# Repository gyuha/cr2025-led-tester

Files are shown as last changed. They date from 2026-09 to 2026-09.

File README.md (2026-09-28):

# cr2025-led-tester
CR2025 LED Tester - 3D Printer

CR2025 코인셀 하나와 파란 5mm LED로, 검사 기판에 납땜된 **1N4148WS(SOD-323) 다이오드의 방향**을 확인하는 3D 프린팅 테스터입니다. 노즈 끝의 두 철사를 다이오드 양쪽 패드에 대면, 방향이 맞을 때 위쪽 LED가 켜집니다. 납땜 없이 LED·저항에서 잘라낸 다리를 케이스 홈에 눌러 끼워 만듭니다.

## 파일

| 파일 | 내용 |
|---|---|
| `stl/tester.stl` | 본체. 배터리 슬롯, LED 받침, 철사 홈, 노즈 |
| `stl/cover.stl` | 케이블 커버. 노즈 구간의 철사를 덮어 누르는 별도 부품 |
| `stl/nose-coupon.stl` | 노즈 시험편. 프로브 간격과 홈 폭을 맞출 때만 씁니다 |
| [docs/assembly.md](docs/assembly.md) | 조립·사용 안내 전체 (인쇄 설정, 조립 순서, 판정 규칙, 문제 해결) |
| [docs/coupon.md](docs/coupon.md) | 노즈 시험편 사용법과 결과 기록 (간격 2.2mm, 홈 폭 0.5mm로 확정) |
| `cad/` | 모델 원본. FreeCAD `freecadcmd`로 실행하는 Python 스크립트와 치수 검사 |

## 준비물

- **인쇄**: `stl/tester.stl`, `stl/cover.stl`
  - Bambu, PLA, 0.4mm 노즐, 레이어 0.12–0.16mm, 서포트 없음
  - 본체는 평평한 뒷면을 바닥에, 커버는 파일 그대로(판이 바닥, 핀이 위) 놓습니다.
- **부품**: CR2025 1개, 파란 5mm LED 1개, 잘라낸 다리 2가닥
  - 연장 다리 A는 약 32mm, 철사 B는 약 30mm가 필요합니다. 짧으면 Ø0.5 구리 단선도 괜찮습니다.
- **도구**: 니퍼, 롱노즈 플라이어, 핀셋

## 철사 연결 방법

철사 4가닥을 케이스 홈에 눌러 끼우고, 노즈 구간은 케이블 커버로 덮은 뒤, **배터리는 맨 마지막에** 넣습니다. 아래 그림은 실제 모델(`stl/tester.stl`, `stl/cover.stl`)에 철사를 색깔별로 그려 넣은 것입니다.

| 색 | 철사 | 가는 곳 |
|---|---|---|
| 🔴 빨강 | **② 애노드 다리**: LED 긴 다리 | 뒤쪽 터널 → 배터리 자리 안쪽 뒷벽 홈 → 배터리 **뒷면(+)** |
| 🟠 주황 | **캐소드 다리**: LED 짧은 다리 | 앞면 홈 A → ① 이음부 |
| 🟡 노랑 | **① 연장 다리 A**: 잘라낸 다리 1가닥 | 이음부에서 주황과 나란히 → 홈 A → 노즈 끝 **A** (▶ 쪽) |
| 🟢 초록 | **③ 철사 B**: 잘라낸 다리 1가닥 | 노즈 끝 **B** (\| 쪽) → 홈 B → ③ 통과 구멍 → 천장 접촉 홈에서 배터리 **앞면(−)**에 선으로 닿음 |

### 완성된 모습 (정면, 홈이 있는 면)

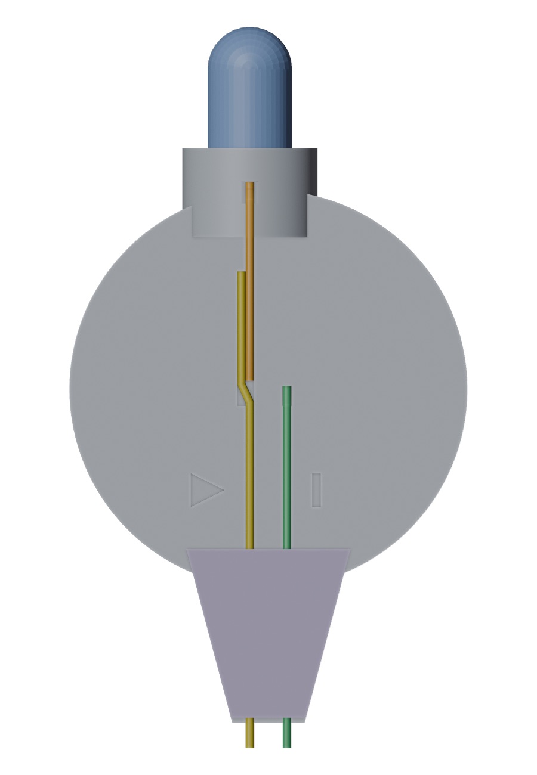
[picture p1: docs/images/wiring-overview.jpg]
철사를 모두 넣은 정면


- 맨 위가 **LED**입니다. 주황 캐소드 다리가 앞면 **홈 A**로 내려옵니다.
- 홈이 두 배로 넓은 구간이 **① 이음부**입니다. 여기서 노랑 연장 다리가 주황 옆에 나란히 눌려 이어지고, 노즈 끝 **A**까지 내려갑니다.
- 노즈 구간(약 10mm)은 별도 부품인 **케이블 커버**(보라색)가 덮습니다. 노랑과 초록을 열린 홈에 올려놓고 커버를 꽂으면, 끝으로 패드를 눌러도 철사가 빠지지 않습니다. 그래서 정면 그림에서는 노즈 속 철사가 커버에 가려 끝에서만 보입니다.
- 초록 철사 B는 오른쪽 홈 B에 들어갑니다. 홈 B가 끝나는 곳의 작은 구멍이 **③ 통과 구멍**입니다. 철사 B의 끝 5mm는 이 구멍을 비스듬히 지나 앞판 안쪽 천장의 접촉 홈에 눕고, 배터리 (−) 면에 선으로 닿습니다. 반대쪽 끝은 노즈 **B**입니다.
- 빨강 애노드 다리는 앞판에 가려 정면에서는 보이지 않습니다. 아래 2단계의 단면 그림을 보세요.

전류는 다음 순서로 흐릅니다.

```
배터리(+) → 빨강 → LED → 주황 → 노랑 → 끝 A → 측정 대상 다이오드 → 끝 B → 초록 → 배터리(−)
```

### 1. LED 다리 벌리기

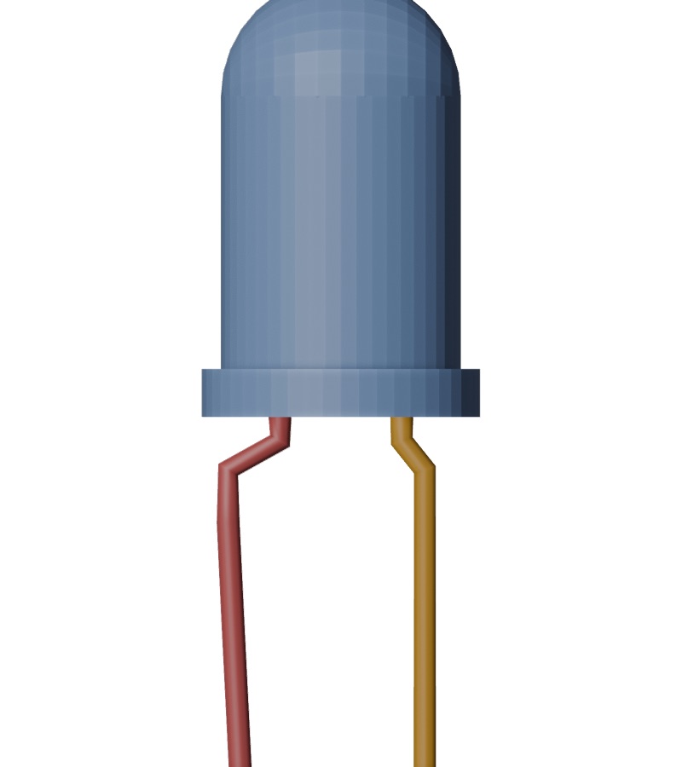
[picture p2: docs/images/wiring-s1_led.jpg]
LED 다리를 앞뒤로 벌린 모습


옆에서 본 모습입니다(왼쪽 = 케이스 뒤, 오른쪽 = 앞). 플랜지 바로 아래에서 **긴 다리(애노드, 빨강)**를 **뒤로 약 1mm**, **짧은 다리(캐소드, 주황)**를 **앞으로 약 0.5mm** 꺾습니다. 캐소드는 LED 플랜지의 **평평한 쪽**에 있는 다리입니다.

### 2. LED 꽂기와 ② 애노드 다리 (단면)

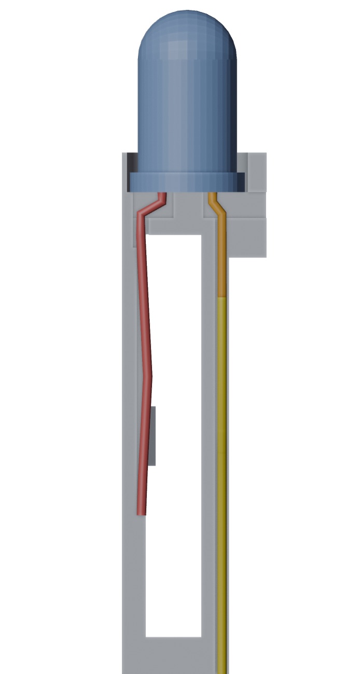
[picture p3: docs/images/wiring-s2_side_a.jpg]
LED 줄에서 자른 단면: 애노드와 캐소드 경로


케이스를 LED 줄에서 세로로 자른 단면입니다. 왼쪽이 뒤, 오른쪽이 앞이고, 가운데 빈 곳이 배터리 자리입니다.

- LED를 받침 위에서 내려 꽂습니다.
- **빨강**은 뒤쪽 터널을 지나 배터리 자리 안쪽 **뒷벽 홈**을 따라 내려갑니다. **주황**은 앞면 홈 A로 들어갑니다.
- 빨강은 홈 끝(배터리 중심에서 약 4mm 아래)에서 자르고, 가운데를 배터리 쪽으로 **약 0.5mm 활처럼** 휘게 합니다. 이 휨이 배터리 (+) 면을 누르는 스프링입니다.

### 3. ① 이음부: 주황 + 노랑

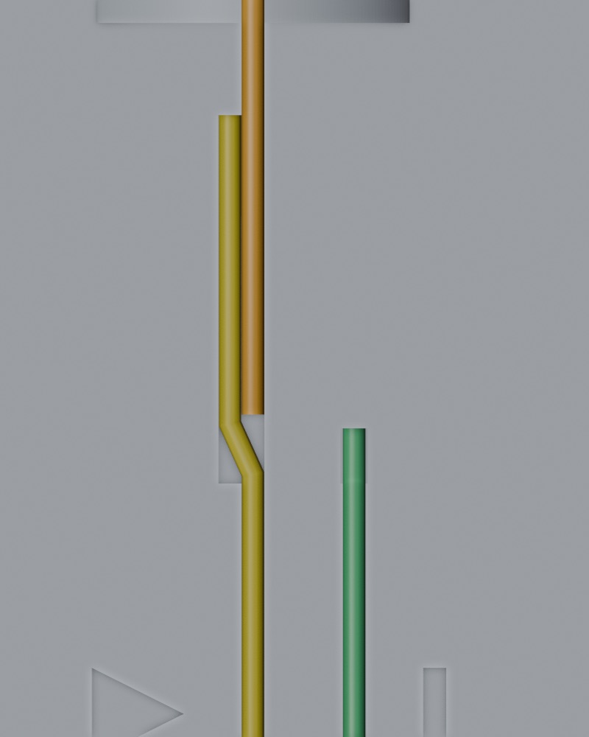
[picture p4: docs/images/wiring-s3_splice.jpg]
이음부 확대: 주황과 노랑이 나란히


- **주황**은 넓은 구간의 아래쪽 끝보다 **약 1.5mm 위**에서 자릅니다.
- **노랑**(약 32mm 다리)은 넓은 구간 위쪽 끝부터 주황 **왼쪽 옆에 나란히** 눌러 넣습니다.
- 주황이 끝난 아래에서 홈 가운데로 살짝 옮긴 뒤, 홈 A를 따라 노즈 끝까지 **위에서 눌러** 넣습니다.
- 노즈 끝으로 나온 부분은 **1.5mm** 남기고 **사선으로** 자릅니다.

두 다리가 약 6mm 맞붙어 전기가 통합니다.

### 4. ③ 철사 B: 통과 구멍을 지나 천장 홈에 눕히기 (단면)

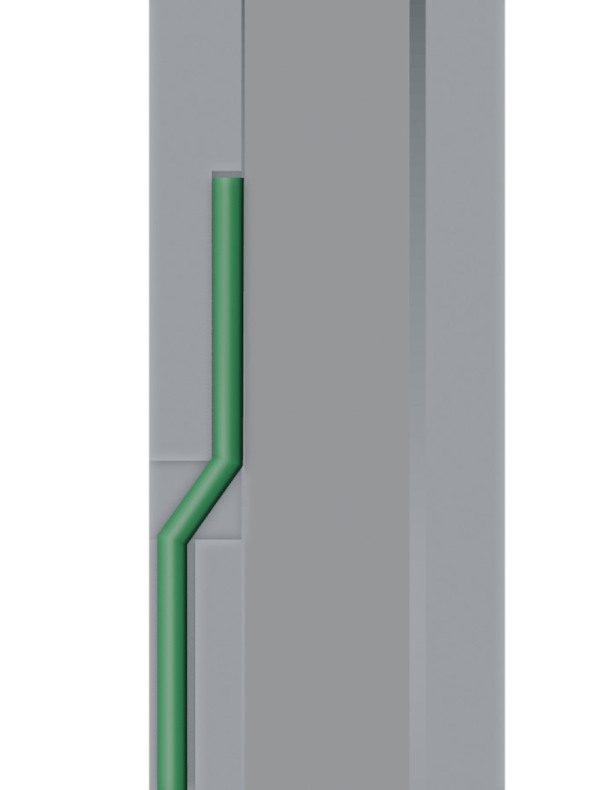
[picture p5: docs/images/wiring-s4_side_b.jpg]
철사 B 줄에서 자른 단면: 통과 구멍을 지나 천장 홈에 누운 끝 5mm


철사 B 줄에서 자른 단면입니다. 왼쪽이 앞, 오른쪽이 뒤이고, 가운데 진한 회색이 배터리입니다.

- 잘라낸 다리(약 30mm)의 한쪽 끝에서 **약 5mm**, **약 6mm** 되는 두 곳을 반대 방향으로 조금씩 꺾어 **계단(크랭크) 모양**을 만듭니다. 끝 5mm가 나머지보다 약 0.9mm 낮아집니다.
- 끝 5mm를 ③ 통과 구멍으로 **위쪽을 향해 비스듬히** 밀어 넣습니다. 그다음 슬롯 쪽에서 핀셋으로 천장 안쪽 **접촉 홈**에 눌러 눕힙니다.
- 배터리를 넣으면 뒤쪽 빨강의 휨이 배터리를 앞으로 밀어, 누운 약 4.4mm 구간 전체가 배터리 **앞면(−)**에 **선으로** 닿습니다.
- 나머지는 구멍에서 노즈 끝까지 홈 B에 **위에서 눌러** 넣고, 노즈 끝으로 나온 부분은 1.5mm 남겨 사선으로 자릅니다.

### 5. 케이블 커버 덮기

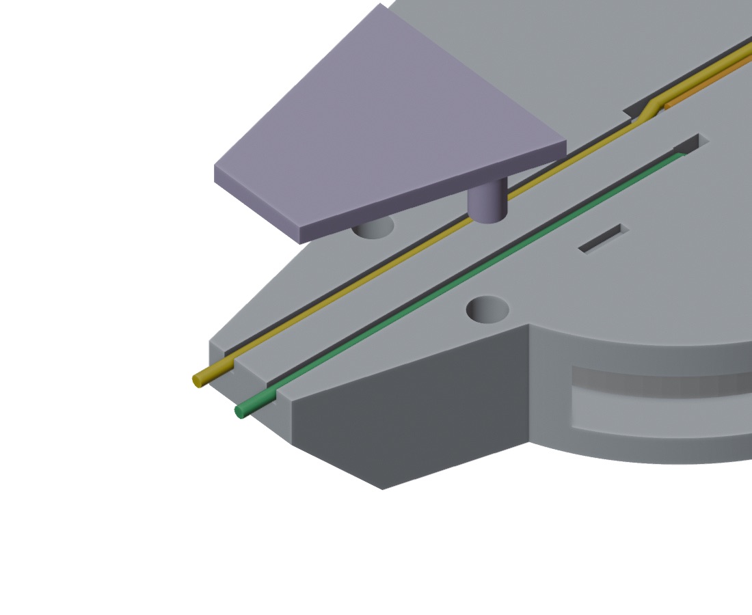
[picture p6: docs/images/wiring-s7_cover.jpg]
케이블 커버를 노즈에 덮는 분해도


케이블 커버(`stl/cover.stl`)는 노즈 앞면을 덮는 0.8mm 판에 핀 2개가 달린 별도 부품입니다.

- 노랑과 초록을 홈에 다 넣은 뒤, 커버의 판이 노즈 앞면을 향하게 하고 **핀 2개를 노즈 윗부분의 고정 구멍**에 맞춰 끝까지 눌러 꽂습니다.
- 판이 노즈 구간의 두 철사를 홈 속으로 눌러 잡습니다. 커버는 노즈 끝 0.3mm 앞에서 끝나서, 철사 끝 1.5mm는 그대로 나옵니다.
- 철사를 고칠 때는 커버 가장자리를 손톱으로 들어 빼면 됩니다.
- 핀이 너무 빡빡하면 Ø1.5 드릴로 구멍을 한 번 돌려 주고, 헐거우면 핀에 테이프를 한 겹 감습니다.

### 6. 배터리는 맨 마지막 → 오른쪽 슬롯

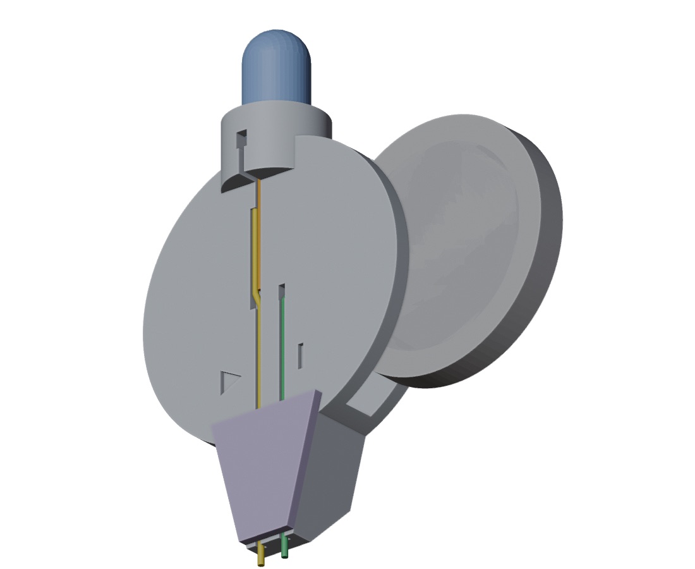
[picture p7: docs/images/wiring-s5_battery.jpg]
배터리를 오른쪽 슬롯으로 밀어 넣기


각인이 있는 **(+) 면을 뒤(바닥 쪽)**, 작은 **(−) 면을 앞(홈 쪽)**으로 두고, 정면에서 볼 때 **오른쪽 옆 틈**으로 밀어 넣습니다. 배터리는 빨강 스프링과 천장에 누운 초록 사이로 들어가고, 뒷판의 턱을 넘으면서 **딸깍** 걸립니다. 배터리를 먼저 넣으면 빨강과 초록을 넣을 수 없습니다.

### 7. 뒷면: 배터리 빼기와 자가 진단

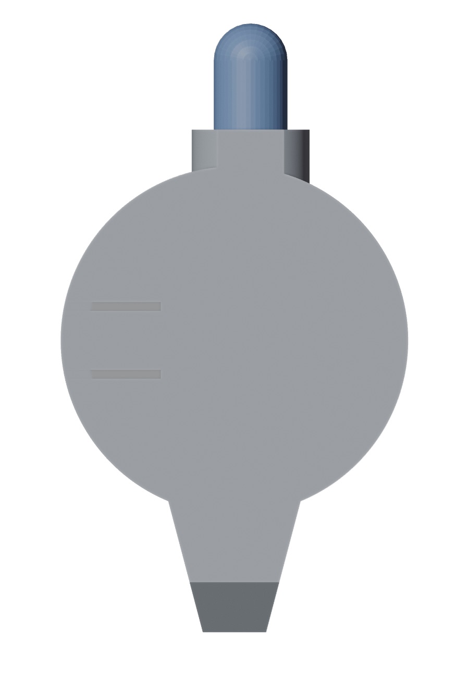
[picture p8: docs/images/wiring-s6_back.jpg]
뒷면: 혀와 두 줄 틈


- 뒤에서 보면 좌우가 뒤집혀 슬롯이 왼쪽에 있습니다. **두 줄 틈 사이의 혀**를 손톱으로 누르면 턱이 내려가 배터리를 밀어낼 수 있습니다.
- 조립이 끝나면 **끝 A와 B를 맞대 보세요**. LED가 켜지면 정상입니다(자가 진단).
- 1분 뒤 배터리가 따뜻하면 초록이 배터리 테두리에 닿은 것입니다. 바로 배터리를 빼세요.

```
LED 다리 벌리기 → LED 꽂기·빨강 → 주황 자르기·노랑 잇기 → 초록 계단·천장 홈 → 케이블 커버 → 배터리 → 자가 진단
```

## 사용과 판정

**기판 전원을 끈 뒤**, 확대경으로 보면서 노즈 끝 두 철사를 1N4148WS 양쪽 패드(몸체 밖으로 드러난 납땜부)에 동시에 댑니다. 그다음 테스터를 180° 돌려 한 번 더 대 보고, 두 번의 결과를 함께 읽습니다.

| 처음 | 180° 돌려서 | 판정 |
|---|---|---|
| 켜짐 | 꺼짐 | 처음 댄 방향에서 **A(▶ 쪽)가 애노드**, B(\| 쪽)가 캐소드입니다. 다이오드의 띠는 B 쪽에 있어야 합니다. |
| 꺼짐 | 켜짐 | 돌려 댄 방향에서 A 쪽이 애노드입니다. 처음 예상과 반대로 실장된 것입니다. |
| 켜짐 | 켜짐 | **판정 불가**. 단락, 솔더 브리지, 또는 병렬로 연결된 부품(대략 10kΩ 이하) 때문입니다. |
| 꺼짐 | 꺼짐 | 개방, 접촉 불량, 또는 테스터 문제입니다. 먼저 끝 A와 B를 맞대 자가 진단을 합니다. |

```mermaid
flowchart TD
    S[기판 전원 끄고 A·B를 패드에 대기] --> Q1{LED 켜짐?}
    Q1 -- 예 --> R2[180° 돌려 다시 대기]
    Q1 -- 아니오 --> R3[180° 돌려 다시 대기]
    R2 --> Q2{켜짐?}
    R3 --> Q3{켜짐?}
    Q2 -- 아니오 --> OK[처음 댄 방향: A 쪽이 애노드]
    Q2 -- 예 --> NA[판정 불가]
    Q3 -- 예 --> REV[돌려 댄 방향: A 쪽이 애노드]
    Q3 -- 아니오 --> OPEN[양방향 꺼짐: 자가 진단 먼저]
    classDef ok fill:#d4f4dd,stroke:#2e7d32;
    classDef warn fill:#fff3cd,stroke:#b8860b;
    classDef bad fill:#f8d7da,stroke:#c0392b;
    class OK,REV ok;
    class NA warn;
    class OPEN bad;
```

인쇄 설정의 자세한 내용, 문제 해결, 파란 LED가 희미할 때의 대처는 [docs/assembly.md](docs/assembly.md)에 있습니다.

## 모델 수정과 검사

치수는 모두 `cad/params.py`에 있습니다. 예를 들어 프로브 간격은 `PROBE_SPACING`, 홈 폭은 `GROOVE_W`, 커버 핀과 구멍은 `PEG_D`, `PEG_HOLE_D`입니다. 값을 고친 뒤 아래 두 명령을 실행하면 `stl/tester.stl`, `stl/cover.stl`, `cad/tester.FCStd`가 새로 만들어지고, 검사 스크립트가 STL을 직접 재서 확인합니다.

```sh
FC=/Applications/FreeCAD.app/Contents/Resources/bin/freecadcmd
$FC cad/tester.py         # → BUILD OK
$FC cad/check_tester.py   # → CHECK OK (포켓, 프로브 간격, 절연층, (−) 접촉, LED 자리, 커버 핀·구멍 정렬)
```

`freecadcmd`는 실패해도 종료 코드 0을 돌려줍니다. 그래서 성공 여부는 반드시 출력 줄(`BUILD OK`, `CHECK OK`)로 판단합니다.

```
cad/params.py 수정 → tester.py 실행 (BUILD OK) → check_tester.py 실행 (CHECK OK) → 인쇄
```

## 인쇄 후 확인할 점

- **파란 LED의 밝기**: 시험편에서는 충분했지만, 배터리가 닳으면 먼저 희미해집니다. 희미하면 빨간 5mm LED로 바꿉니다. 본체를 다시 인쇄할 필요는 없습니다.
- **프로브 간격 2.2mm**: 시험한 범위(2.2–2.6)의 가장 작은 값입니다. 끝이 SOD-323 몸체 가장자리를 누르면 `PROBE_SPACING`을 조금 넓힙니다.
- **(−) 접촉 위치**: 철사 B는 배터리 중심에서 약 5mm 안쪽에서 (−) 면에 닿습니다. 쓰는 CR2025의 (−) 면 평평한 부분이 이보다 넓은지 확인합니다.
- **커버 핀 끼움 정도**: 너무 빡빡하면 Ø1.5 드릴로 구멍을 한 번 돌리고, 헐거우면 핀에 테이프를 한 겹 감습니다.

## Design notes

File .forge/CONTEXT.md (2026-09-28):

# CR2025 LED 극성 테스터

CR2025 코인셀 하나와 표시 LED로, 검사 기판에 납땜된 다이오드의 방향을 확인하는 3D 프린팅 도구.

## Language

### 회로와 판정

**표시 LED**:
테스터에 직렬로 들어가 켜짐/꺼짐으로 판정 결과를 보여주는 LED.
_Avoid_: 테스트 LED, 인디케이터

**측정 대상 다이오드**:
극성을 확인하려는 다이오드. 이 프로젝트에서는 검사 기판에 실장된 1N4148WS(SOD-323).
_Avoid_: 테스트 다이오드, DUT(문서에서는 풀어 씀)

**프로브 A**:
표시 LED를 거쳐 배터리 (+)에 이어지는 끝. 측정 대상 다이오드의 애노드가 여기에 닿으면 표시 LED가 켜진다.
_Avoid_: + 프로브, 빨간 프로브

**프로브 B**:
배터리 (−)에 직접 이어지는 끝. 측정 대상 다이오드의 캐소드(띠 쪽)가 닿는 자리.
_Avoid_: − 프로브, 검은 프로브

**인서킷 측정**:
측정 대상 다이오드를 기판에서 떼지 않고 납땜된 채로 판정하는 것.
_Avoid_: 온보드 테스트

**판정 불가**:
양방향 모두 표시 LED가 켜지는 상태. 단락, 솔더 브리지, 또는 병렬로 연결된 부품 경로 때문이며 방향을 알 수 없다.
_Avoid_: 불량(원인이 여러 가지라 단정 불가)

### 기구

**노즈**:
프로브 두 끝을 받쳐 휘지 않게 하는 케이스 아래쪽의 가늘고 뾰족한 돌출부.
_Avoid_: 팁 홀더, 부리

**케이블 커버**:
노즈 구간의 열린 철사 홈을 덮어, 끝으로 패드를 누를 때 철사가 빠지지 않게 누르는 별도 인쇄 부품. 핀 2개로 노즈에 꽂는다.
_Avoid_: 클립, 뚜껑, 노즈 터널(철사를 꿰는 이전 방식)

**프로브 간격**:
프로브 A와 B 끝의 중심 간 거리. 검사 기판에서 측정 대상 다이오드의 두 패드 중심 간 거리와 같아야 한다.
_Avoid_: 피치(부품 리드 간격과 혼동)

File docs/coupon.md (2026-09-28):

# 노즈 시험편 사용 안내

테스터 본체를 인쇄하기 전에, 작은 시험편으로 두 가지 치수를 실물에 맞춰 정합니다. 여기서 정한 값은 본체 모델(`cad/params.py`의 `PROBE_SPACING`, `GROOVE_W`)에 반영됩니다.

- **프로브 간격**: 두 철사 끝의 중심 간 거리입니다. 검사 기판에서 1N4148WS(SOD-323)의 두 패드 중심 간 거리와 같아야 합니다.
- **홈 폭**: 잘라낸 LED·저항 다리가 끝까지 눌려 들어가고, 흔들어도 빠지지 않는 폭입니다.

같은 단계에서 **파란 LED 손 테스트**도 합니다. 파란 LED(Vf 약 2.8–3.3V)와 다이오드(약 0.6–0.7V)를 직렬로 연결하면 합계가 새 CR2025 전압(약 3.2V)과 비슷하거나 더 높습니다. 그래서 LED가 희미하거나 켜지지 않을 수 있으므로 실물로 확인합니다.

## 파일과 인쇄

`stl/nose-coupon.stl` 하나에 조각 4개가 들어 있습니다.

| 조각 | 각인 | 용도 |
|---|---|---|
| 노즈 3개 | `2.2` · `2.4` · `2.6` | 두 홈의 중심 간 거리(mm)가 각각 다릅니다. 홈 폭은 모두 0.6mm입니다. |
| 홈 폭 띠 | `0.4` · `0.5` · `0.6` · `0.7` | 홈 폭(mm)이 다른 홈 4줄입니다. |

- 프린터: Bambu, PLA, 0.4mm 노즐
- 레이어: 0.12–0.16mm를 권장합니다. 홈 깊이가 0.7mm, 각인 깊이가 0.4mm라서 0.2mm 레이어로 뽑으면 둘 다 뭉개질 수 있습니다.
- 방향: 파일 그대로(홈과 각인이 위쪽) 바닥에 눕혀 뽑습니다. 서포트는 필요 없습니다.
- 인쇄 시간은 몇 분 정도입니다.

코드로 다시 만들려면 다음 명령을 실행합니다. 두 명령 모두 결과는 출력 줄(`BUILD OK`, `CHECK OK`)로 판단합니다. `freecadcmd`는 실패해도 종료 코드 0을 돌려주기 때문입니다.

```sh
FC=/Applications/FreeCAD.app/Contents/Resources/bin/freecadcmd
$FC cad/coupon.py         # → BUILD OK stl/nose-coupon.stl
$FC cad/check_coupon.py   # → CHECK OK (간격·홈 폭을 STL 단면에서 직접 잰 값)
```

## 준비물

- 인쇄한 시험편
- 잘라낸 LED·저항 다리 여러 가닥. 끝은 니퍼로 **사선으로 잘라 뾰족하게** 합니다. 플럭스 잔여물을 뚫고 패드에 닿게 하기 위해서입니다.
- 파란 5mm LED 1개, CR2025 1개. 각인이 있는 넓은 면이 (+), 반대쪽 작은 면이 (−)입니다.
- 검사 기판. **전원은 반드시 끕니다.**
- 투명 테이프나 빨래집게, 확대경. 멀티미터는 있으면 좋지만 필수는 아닙니다.

## 확인 순서

세 단계를 차례로 진행합니다. 1단계에서 다리가 홈에 제대로 물리는지 먼저 확인하고, 2단계에서 그 다리를 노즈에 끼워 간격을 고른 뒤, 3단계에서 고른 노즈로 실제 판정을 해 보면서 파란 LED 밝기를 봅니다.

### 1단계 — 홈 폭 고르기

1. 홈 폭 띠의 각 홈에 다리를 한 가닥씩 눌러 넣습니다. 핀셋 뒷면이나 손톱을 쓰면 됩니다.
2. 기준:
   - 다리가 윗면 아래로 **끝까지 묻혀야** 합니다.
   - 띠를 뒤집어 흔들어도 **빠지지 않아야** 합니다.
   - 너무 좁으면 끝까지 들어가지 않거나 플라스틱이 갈라집니다.
   - 너무 넓으면 흔들 때 빠집니다.
3. 두 조건을 모두 만족하는 폭 중 **가장 좁은 것**을 고릅니다. 이것이 **선택한 홈 폭**입니다.

LED 다리는 단면이 네모(약 0.5 × 0.5mm)인 경우가 많고, 저항 다리는 원형입니다. 실제로 쓸 다리로 확인하세요.

### 2단계 — 프로브 간격 고르기

1. 노즈 3개에 다리를 두 가닥씩 끼웁니다. 노즈 끝 밖으로 약 **1.5mm**가 나오게 하고, 뒤쪽(손잡이 쪽)은 길게 남겨 둡니다.
   - 노즈 홈 폭은 0.6mm로 고정되어 있습니다. 1단계에서 고른 폭이 0.6이 아니면 다리가 헐겁거나 빡빡할 수 있습니다. 이때는 테이프로 임시 고정하고 **간격만** 판단합니다.
2. 기판 전원을 끄고, 확대경으로 보면서 노즈 끝을 1N4148WS에 댑니다. 두 다리 끝이 몸체 양쪽 바깥으로 드러난 **패드(납땜부) 위에 동시에** 올라가야 합니다.
3. 기준:
   - 두 끝이 모두 패드 위에 있어야 합니다.
   - 몸체(검은 부분)를 누르면 안 됩니다. 몸체는 절연체라 닿아도 반응이 없습니다.
   - 옆 부품을 건드리면 안 됩니다.
4. (선택) 멀티미터를 다이오드 모드로 두고 두 다리의 뒤쪽 끝 사이를 잽니다. 한 방향으로 약 0.5–0.7V가 나오면 두 끝이 모두 접촉한 것입니다.
5. 가장 안정적으로 닿는 노즈의 각인 값이 **선택한 프로브 간격**입니다.

### 3단계 — 파란 LED 손 테스트

2단계에서 고른 노즈를 그대로 써서, 실제 테스터와 같은 회로를 손으로 만듭니다.

1. 노즈 뒤쪽으로 나온 **다리 A**(노즈에 새긴 숫자를 바로 읽었을 때 왼쪽)를 파란 LED의 **짧은 다리(캐소드)**에 꼬아 잇습니다.
2. LED의 **긴 다리(애노드)**는 배터리 **(+) 면**에, **다리 B**의 뒤쪽 끝은 배터리 **(−) 면**에 대고 빨래집게나 테이프로 고정합니다. 두 다리가 배터리 옆 테두리에 닿지 않게 하세요. 테두리는 (+)이므로 다리 B가 닿으면 단락됩니다.
3. 자가 진단: 노즈 끝의 두 다리를 서로 맞대면 LED가 켜져야 합니다. 켜지지 않으면 배선부터 다시 확인합니다.
4. 노즈 끝을 기판의 1N4148WS 패드에 댑니다. 한 방향에서 켜지고, 180° 돌려 대면 꺼지는지 봅니다.
5. 실내 조명에서 켜진 밝기를 판단합니다.
   - **밝기 충분**: 파란 LED를 그대로 씁니다.
   - **희미함** 또는 **안 켜짐**: 빨간 5mm LED로 바꿔 같은 순서를 반복합니다. LED 구멍은 표준 5mm라서 본체를 다시 설계할 필요가 없습니다.

양방향 모두 켜지면 **판정 불가**입니다. 단락, 솔더 브리지, 또는 병렬로 연결된 부품 때문입니다. 이 경우는 간격 문제가 아니므로 다른 다이오드로 확인하세요.

```
1단계 홈 폭 → 2단계 간격 (노즈 3종 비교) → 3단계 고른 노즈로 판정 + 파란 LED 밝기
                                                   ↓ 희미 / 안 켜짐
                                             빨간 LED로 바꿔 3단계 반복
```

## 결과 기록

확인이 끝나면 아래 칸을 채웁니다. 본체 모델(계획 2/2)이 이 값을 씁니다.

- 선택한 프로브 간격: **2.2** mm (2.2 / 2.4 / 2.6)
- 선택한 홈 폭: **0.5** mm (0.4 / 0.5 / 0.6 / 0.7)
- 파란 LED 손 테스트: **밝기 충분** → 표시 LED 색: **파랑**
- 사용한 다리: LED 다리(네모) / 저항 다리(둥근), 굵기 ______ mm (미기록)
- 메모 (세 노즈 모두 맞지 않았다면 어느 쪽으로 벗어났는지 등): 2026-09-28 확인. 2.2는 시험 범위의 하한이라 더 좁은 간격(2.0 등)은 시험하지 않았다.

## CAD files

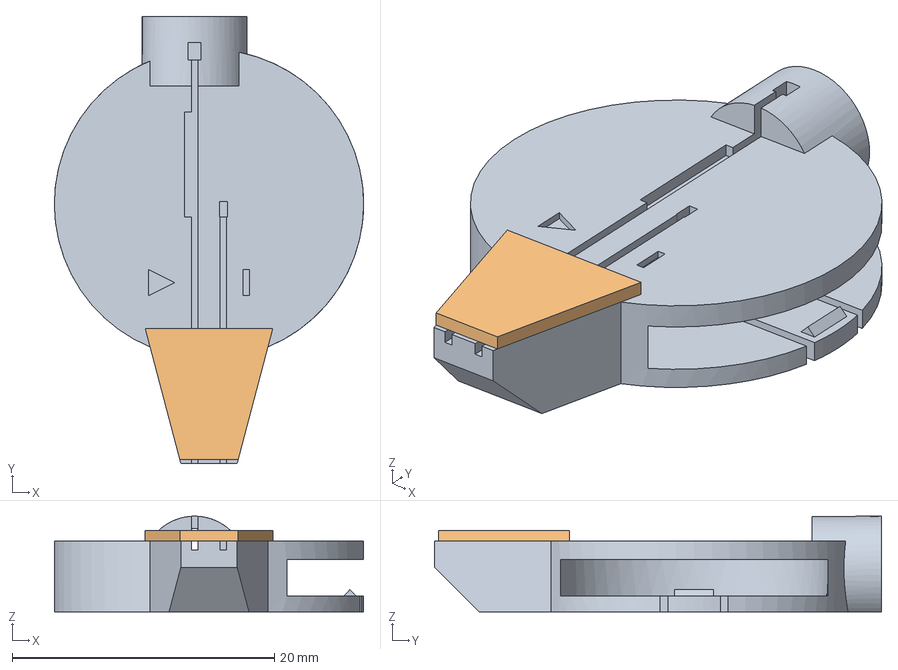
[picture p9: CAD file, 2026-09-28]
cad/tester.FCStd
23.6 x 34.1 x 7.30 mm
Tester
CableCover

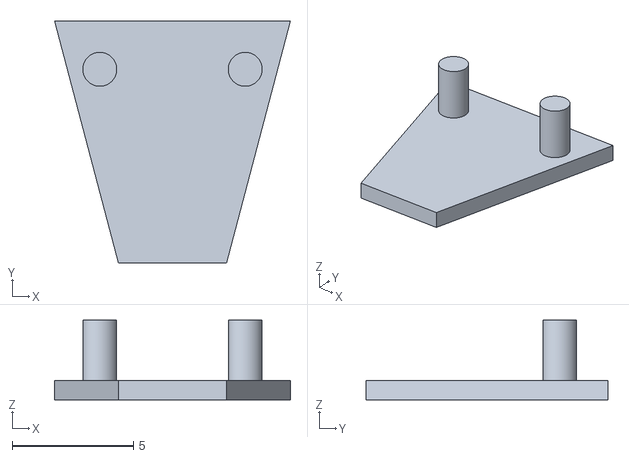
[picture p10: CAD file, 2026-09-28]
stl/cover.stl
9.74 x 10.0 x 3.30

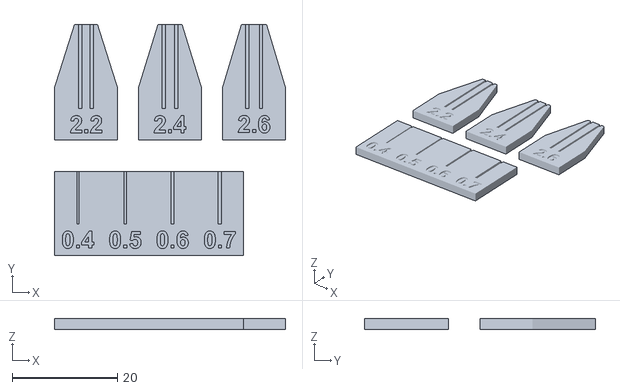
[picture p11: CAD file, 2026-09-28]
stl/nose-coupon.stl
44.0 x 44.0 x 2.00

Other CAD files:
stl/tester.stl

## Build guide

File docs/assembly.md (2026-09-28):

# CR2025 극성 테스터 조립·사용 안내

CR2025 하나와 파란 5mm LED로, 검사 기판에 납땜된 1N4148WS(SOD-323)의 방향을 확인하는 도구입니다. 노즈 끝의 두 철사를 다이오드 양쪽 패드에 대면, 방향이 맞을 때 위쪽 LED가 켜집니다. 납땜은 필요 없습니다. 모든 철사는 케이스 홈에 눌러 끼웁니다.

## 구조

정면(홈이 있는 면)에서 볼 때 기준입니다. LED는 위, 노즈는 아래, 배터리 슬롯은 오른쪽에 있습니다.

| 표시 | 부위 | 역할 |
|---|---|---|
| ① | 철사 A 홈의 이음부(홈이 두 배로 넓은 8mm 구간) | LED 캐소드 다리와 연장 다리를 나란히 눌러 잇습니다. |
| ② | 뒷벽 안쪽의 애노드 홈 | LED 애노드 다리가 배터리 **뒷면(+)**을 누릅니다. |
| ③ | 홈 B 끝의 통과 구멍(0.6 × 1.2mm)과 앞판 안쪽 천장의 접촉 홈 | 철사 B가 구멍을 비스듬히 지나 천장 홈에 눕고, 약 4.4mm 구간이 배터리 **앞면(−)**에 선으로 닿습니다. |
| 케이블 커버 | 노즈 앞면을 덮는 별도 부품(`stl/cover.stl`)과 노즈 윗부분의 고정 구멍 2개 | 철사를 홈에 올려놓은 뒤 커버 핀 2개를 구멍에 꽂아 덮습니다. 끝으로 패드를 눌러도 철사가 빠지지 않습니다. |
| A / B | 노즈 끝 왼쪽 / 오른쪽 철사 | 프로브 A, 프로브 B. 간격은 2.2mm입니다. |
| ▶ / \| | 앞면 각인. 삼각형은 A 왼쪽, 막대는 B 오른쪽 | LED가 켜졌을 때 다이오드 기호가 가리키는 방향입니다. |
| 혀와 턱 | 뒷판 오른쪽의 갈라진 혀와 그 위의 작은 턱 | 배터리가 빠지지 않게 붙잡는 걸림턱입니다. |

어떤 철사도 배터리의 옆 테두리나 (−) 면 가장자리에 닿지 않도록 홈이 플라스틱으로 절연되어 있습니다. 그 두께는 0.7mm로, `cad/check_tester.py`가 확인합니다. CR2025의 (+) 캔은 옆 테두리를 감싸고 (−) 면 가장자리까지 말려 올라와 있어서, 철사 B가 테두리에 닿으면 배터리가 단락됩니다.

전류는 다음 순서로 흐릅니다.

```
배터리 뒷면(+) → ② 애노드 다리 → 파란 LED → ① 철사 A → 끝 A → 측정 대상 다이오드 → 끝 B → 철사 B → ③ 통과 구멍 → 천장 접촉 홈 → 배터리 앞면(−)
```

## 부품

- 인쇄한 본체 `stl/tester.stl`, 케이블 커버 `stl/cover.stl`
- CR2025 1개
- 파란 5mm LED 1개. 시험편에서 밝기 충분을 확인했습니다.
- 잘라낸 다리 2가닥. 끝을 자를 여유를 두어 연장 다리 A는 **약 32mm**, 철사 B는 **약 30mm**로 준비합니다. 1/4W 저항 다리가 짧으면 같은 굵기(Ø0.5)의 구리 단선을 써도 됩니다. A와 B는 스프링 역할이 없어서 무른 철사도 괜찮습니다.
- 니퍼, 롱노즈 플라이어, 핀셋

## 인쇄

- 프린터: Bambu, PLA, 0.4mm 노즐
- 레이어: 0.12–0.16mm. 홈 깊이가 0.7mm, 각인 깊이가 0.4mm입니다.
- 방향: **평평한 뒷면을 바닥에** 둡니다. 서포트는 필요 없습니다.
  - 배터리 포켓 천장은 약 20mm를 가로지르는 브리지로 인쇄됩니다. 천장이 처지면 배터리가 빡빡해질 수 있습니다.
  - 노즈 끝 뒷면은 45°로 깎여 있어 서포트 없이 인쇄됩니다.
- 케이블 커버는 파일 그대로(판이 바닥, 핀 2개가 위) 인쇄합니다. 서포트는 필요 없습니다.
  - 핀(Ø1.4)과 본체 고정 구멍(Ø1.5)은 세로 구멍이 인쇄 중 약간 좁아지는 것을 감안해 꽉 끼도록 잡았습니다 [중간].
  - 너무 빡빡하면 Ø1.5 드릴로 구멍을 한 번 돌려 주고, 헐거우면 핀에 테이프를 한 겹 감거나 순간접착제를 조금 바릅니다.
- 크기는 약 23.6 × 34.1 × 7.3mm입니다.

코드로 다시 만들려면 다음 명령을 실행합니다. 두 명령 모두 결과는 출력 줄(`BUILD OK`, `CHECK OK`)로 판단합니다. `freecadcmd`는 실패해도 종료 코드 0을 돌려주기 때문입니다.

```sh
FC=/Applications/FreeCAD.app/Contents/Resources/bin/freecadcmd
$FC cad/tester.py         # → BUILD OK stl/tester.stl + cad/tester.FCStd
$FC cad/check_tester.py   # → CHECK OK (포켓·간격·절연층·통과 구멍 크기·(−) 접촉 길이와 위치·LED 자리를 STL에서 직접 잰 값)
```

치수를 바꾸려면 `cad/params.py`를 고친 뒤 위 두 명령을 다시 실행합니다. 프로브 간격(`PROBE_SPACING`)과 홈 폭(`GROOVE_W`)은 노즈 시험편 결과(`docs/coupon.md`)로 정한 값입니다.

## 조립

순서가 중요합니다. **배터리는 맨 마지막에 넣습니다.** 먼저 넣으면 ②와 ③ 다리를 넣을 수 없습니다.

1. **LED 다리 벌리기.** LED 플랜지의 평평한 쪽이 캐소드(짧은 다리)입니다. 캐소드를 **앞(홈 쪽)**, 애노드(긴 다리)를 **뒤**로 둡니다. 플랜지 바로 아래에서 애노드는 뒤로 약 1mm, 캐소드는 앞으로 약 0.5mm 벌립니다.
2. **LED 꽂기.** 받침 위에서 LED를 내려 꽂습니다. 애노드는 뒤쪽 깔때기와 터널로, 캐소드는 앞쪽 슬롯(홈 A)으로 들어갑니다. 플랜지가 자리 바닥에 닿을 때까지 누릅니다.
3. **② 애노드 다리.** 터널을 지난 다리는 배터리 슬롯 안쪽 뒷벽의 홈을 따라 내려갑니다.
   - 홈 끝(배터리 중심에서 약 4mm 아래)에 맞춰 자릅니다.
   - 슬롯 쪽에서 보면서 다리 가운데를 배터리 쪽으로 약 0.5mm 활처럼 휘게 합니다. 이 휨이 배터리를 누르는 스프링이 됩니다.
4. **캐소드 다리.** 홈 A에 핀셋 뒷면으로 눌러 넣고, ① 이음부의 아래쪽 끝보다 **약 1.5mm 위**에서 자릅니다. 연장 다리가 그 아래 공간에서 홈 가운데로 옮겨 가야 하기 때문입니다.
5. **① 연장 다리 A.**
   - 잘라낸 다리 한 가닥을 이음부 위쪽 끝부터 캐소드 다리 **옆에 나란히** 눌러 넣습니다.
   - 캐소드 다리가 끝난 곳 아래에서 홈 가운데로 살짝 옮긴 뒤, 홈 A를 따라 노즈 끝까지 **위에서 눌러** 넣습니다.
   - 노즈 끝으로 나온 부분은 **1.5mm** 남기고 **사선으로** 자릅니다. 사선 끝이 플럭스 잔여물을 뚫습니다.
6. **③ 철사 B.** 잘라낸 다리 한 가닥의 한쪽 끝에서 **약 5mm**, **약 6mm** 되는 두 곳을 서로 반대 방향으로 조금씩 꺾습니다. 끝 5mm가 나머지보다 약 0.9mm 낮은 **계단(크랭크) 모양**이 됩니다(README 그림 4).
   - 끝 5mm를 ③ 통과 구멍(홈 B 위쪽 끝의 0.6 × 1.2mm 구멍)으로 **위쪽을 향해 비스듬히** 밀어 넣습니다.
   - 슬롯 쪽에서 핀셋으로 끝 5mm를 배터리 자리 천장 안쪽의 **접촉 홈**(구멍에서 위로 약 4.4mm)에 눌러 눕힙니다.
   - 나머지는 구멍에서 노즈 끝까지 홈 B에 **위에서 눌러** 넣고, 노즈 끝으로 나온 부분은 1.5mm 남겨 사선으로 자릅니다.
   - 배터리를 넣으면 뒤쪽 ② 애노드 휨이 배터리를 앞으로 밀어, 천장 홈에 누운 약 4.4mm 구간 전체가 배터리 (−) 면에 **선으로** 닿습니다.
7. **케이블 커버 덮기.** 커버의 판이 노즈 앞면을 향하게 하고, 핀 2개를 노즈 윗부분의 고정 구멍에 맞춰 끝까지 눌러 꽂습니다. 판이 노즈 구간의 철사 A·B를 홈 속으로 눌러 잡습니다. 철사를 고칠 때는 커버 가장자리를 손톱으로 들어 빼면 됩니다.
8. **배터리 넣기.** 각인이 있는 **(+) 면을 뒤(바닥면)**, **(−) 면을 앞(홈 쪽)**으로 두고, 정면에서 볼 때 **오른쪽 슬롯**으로 밀어 넣습니다. 뒷판 혀의 턱을 넘으면서 딸깍 걸립니다. 꺼낼 때는 뒷면의 혀를 손톱으로 눌러 턱을 내리고 밀어냅니다.
9. **자가 진단.** 끝 A와 B를 맞대면 LED가 켜져야 합니다. 켜지지 않으면 다음을 차례로 확인합니다.
   - 배터리 방향 ((+) 면이 뒤)
   - LED 방향 (캐소드가 앞)
   - ②가 배터리를 누르는 휨
   - ③ 끝 5mm가 천장 접촉 홈에 제대로 누워 있는지
   - ① 이음부의 두 다리가 붙어 있는지
10. **단락 확인.** 조립 후 1분쯤 지나 배터리가 따뜻해지지 않았는지 만져 봅니다. 따뜻하면 철사 B가 배터리 테두리에 닿은 것이니 바로 배터리를 빼세요.

```
LED 다리 벌리기 → LED 꽂기 → ② 애노드 휨·자르기 → 캐소드 자르기 → ① 연장 다리 A → ③ 철사 B → 케이블 커버 → 배터리 → 자가 진단 → 단락 확인
```

## 사용과 판정

1. **기판 전원을 끕니다.** 전원이 켜진 기판에서는 판정이 틀리고 부품이 상할 수 있습니다.
2. 확대경으로 보면서 노즈 끝 두 철사를 1N4148WS 양쪽 패드(몸체 밖으로 드러난 납땜부)에 동시에 댑니다.
3. 결과를 다음 규칙으로 읽습니다.
   - **켜짐**: A(▶ 쪽)에 닿은 패드가 애노드, B(| 쪽)가 캐소드입니다. 각인 ▶|가 그대로 다이오드 기호 방향이고, 다이오드의 띠는 B 쪽에 있어야 합니다.
   - **꺼짐**: 테스터를 180° 돌려 다시 댑니다. 이번에 켜지면 **돌려 댄 방향**에서 A 쪽 패드가 애노드입니다. 처음 예상과 반대로 실장된 것입니다.
   - **양방향 모두 켜짐**: **판정 불가**입니다. 단락, 솔더 브리지, 또는 병렬로 연결된 부품 경로 때문입니다. 병렬 경로가 대략 10kΩ 이하이면 이렇게 될 수 있습니다 [중간]. 부품을 떼어 확인합니다.
   - **양방향 모두 꺼짐**: 개방(다이오드 불량), 접촉 불량, 또는 테스터 문제입니다. 먼저 **자가 진단**으로 테스터가 정상인지 확인하세요.

```mermaid
flowchart TD
    S[기판 전원 끄고 A·B를 패드에 대기] --> Q1{LED 켜짐?}
    Q1 -- 예 --> R2[180° 돌려 다시 대기]
    Q1 -- 아니오 --> R3[180° 돌려 다시 대기]
    R2 --> Q2{켜짐?}
    R3 --> Q3{켜짐?}
    Q2 -- 아니오 --> OK[처음 댄 방향: A 쪽이 애노드, B 쪽이 캐소드]
    Q2 -- 예 --> NA[판정 불가: 단락·솔더 브리지·병렬 경로]
    Q3 -- 예 --> REV[돌려 댄 방향: A 쪽이 애노드]
    Q3 -- 아니오 --> OPEN[양방향 꺼짐: 자가 진단 먼저, 개방·접촉 불량 확인]
    classDef ok fill:#d4f4dd,stroke:#2e7d32;
    classDef warn fill:#fff3cd,stroke:#b8860b;
    classDef bad fill:#f8d7da,stroke:#c0392b;
    class OK,REV ok;
    class NA warn;
    class OPEN bad;
```

## 파란 LED와 배터리

파란 LED(Vf 약 2.8–3.3V)와 다이오드(약 0.6–0.7V)를 직렬로 연결하면 합계가 CR2025 전압(새 배터리 약 3.2V)과 비슷합니다. 시험편에서는 밝기가 충분했지만, **배터리가 닳으면 먼저 희미해집니다.** 새 배터리로 바꿔도 희미하면 빨간 5mm LED로 바꾸세요. 규격이 같은 5mm라 본체를 다시 인쇄할 필요가 없습니다.

## 확인이 더 필요한 가정

- **(−) 면 안전 반경 6mm**: ③ 철사 B가 (−) 면에 닿는 구간은 배터리 중심에서 약 5mm 안쪽입니다. 쓰는 CR2025의 (−) 면 평평한 부분이 이보다 넓은지 한 번 확인하세요.
- **프로브 간격 2.2mm**: 시험한 범위(2.2–2.6)의 가장 작은 값입니다. 끝이 SOD-323 몸체 가장자리를 누르는 것 같으면 `PROBE_SPACING`을 조금 넓혀 다시 인쇄합니다.

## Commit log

2026-09-28 CR2025 다이오드 극성 테스터: 노즈 시험편 + 본체 모델과 조립 안내
    - cad/: FreeCAD freecadcmd 스크립트 (params, 시험편 coupon, 본체 tester) 와
    STL 단면·광선 측정 검사 (check_coupon, check_tester)
    - stl/: nose-coupon.stl, tester.stl (프로브 간격 2.2mm, 홈 폭 0.5mm 반영)
    - docs/: 시험편 사용 안내, 조립·사용 안내, 철사 연결 그림 7장
    - README: 철사 연결 방법 (색깔별 범례 + 단계별 그림)
    - .gitignore: forge 휘발 상태·FreeCAD 백업·macOS 정크 제외
    [nose-coupon.stl, tester.FCStd, tester.stl]
2026-09-28 철사 B (−) 접점을 천장 홈 선 접촉으로 변경
    V자 창은 철사를 붙잡을 곳이 없고, ㄱ자 핀 구멍은 한 점만 닿아 접촉이 부족했다.
    철사 B가 통과 구멍(0.6 x 1.2mm)을 비스듬히 지나 포켓 천장 안쪽 접촉 홈
    (폭 0.6, 깊이 0.45, 길이 4.4mm)에 눕고, 배터리 (−) 면에 선으로 닿는다.
    - cad/: 통과 구멍 + 천장 접촉 홈, 검사에 통과 구멍 크기와 (−) 접촉 길이 추가
    - docs/assembly.md, README: 계단(크랭크) 꺾기 조립법, 필요한 철사 길이
    - docs/images: 철사 연결 그림 7장 다시 렌더링
    [tester.FCStd, tester.stl]
2026-09-28 노즈 철사 고정용 케이블 커버 추가, README 보강
    노즈 구간의 열린 홈만으로는 철사 고정이 어렵고, 터널에 꿰는 방식은 조립이 어려워
    철사를 홈에 올려놓은 뒤 덮는 별도 부품으로 바꿨다.
    - cad/: 노즈 윗부분 고정 구멍 2개(Ø1.5), 케이블 커버(0.8mm 판 + 핀 Ø1.4 2개)
    생성, 커버 핀·구멍 정렬과 노즈 홈 덮음 검사 추가
    - stl/cover.stl: 케이블 커버 (인쇄 방향: 판이 바닥, 핀이 위)
    - docs/assembly.md: 케이블 커버 덮기 단계, 인쇄 시 핀 끼움 대처
    - README: 소개, 파일, 준비물, 사용과 판정, 모델 수정과 검사, 인쇄 후 확인할 점
    - .forge/CONTEXT.m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
    [cover.stl, tester.FCStd, tester.stl]
